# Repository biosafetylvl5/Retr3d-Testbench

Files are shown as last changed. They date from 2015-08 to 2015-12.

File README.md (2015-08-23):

# Retr3d Testbench
**Retr3d Testbench**, or just **Testbench** is an Arduino Mega shield build to enable self-testing. It uses resistors to check the current sinking of each pin after it checks if any pins are stuck HIGH or LOW.

## Images

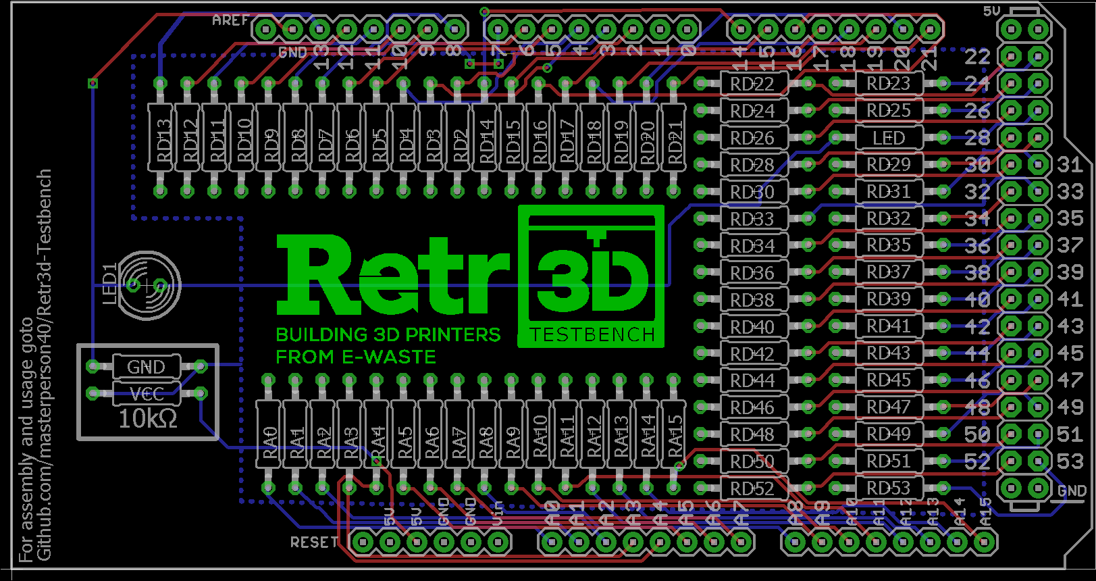
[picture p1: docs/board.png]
Board

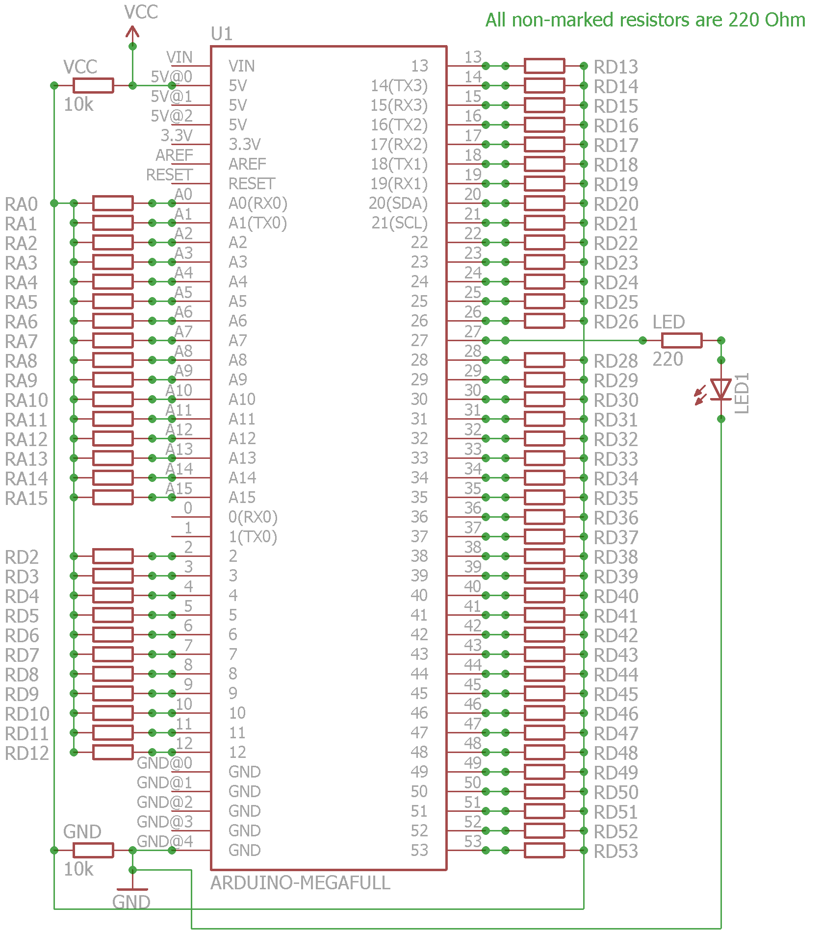
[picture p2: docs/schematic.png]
Schematic


## Origin
**Testbench** was designed to be used in tandem with Retr3d, a framework for designing custom 3D printers to be made out of e-waste. Cheap Arduino Mega clones have a relatively high failure rate, and **Testbench** hopes to find problem boards before they become a problem. With this in mind, certain design choices were made (see **Note 2**) that reflect this origin.

### Notes

##### Note 1:
Pins **0** and **1** are not tested because they must be used to upload the self-testing sketch, and therefore are assumed to be working. 

##### Note 2:

Pin **27** is not tested because it is a pin not utilized in the RAMPS 1.4 3D printer shield and instead is utilized to blink the indicator LED.

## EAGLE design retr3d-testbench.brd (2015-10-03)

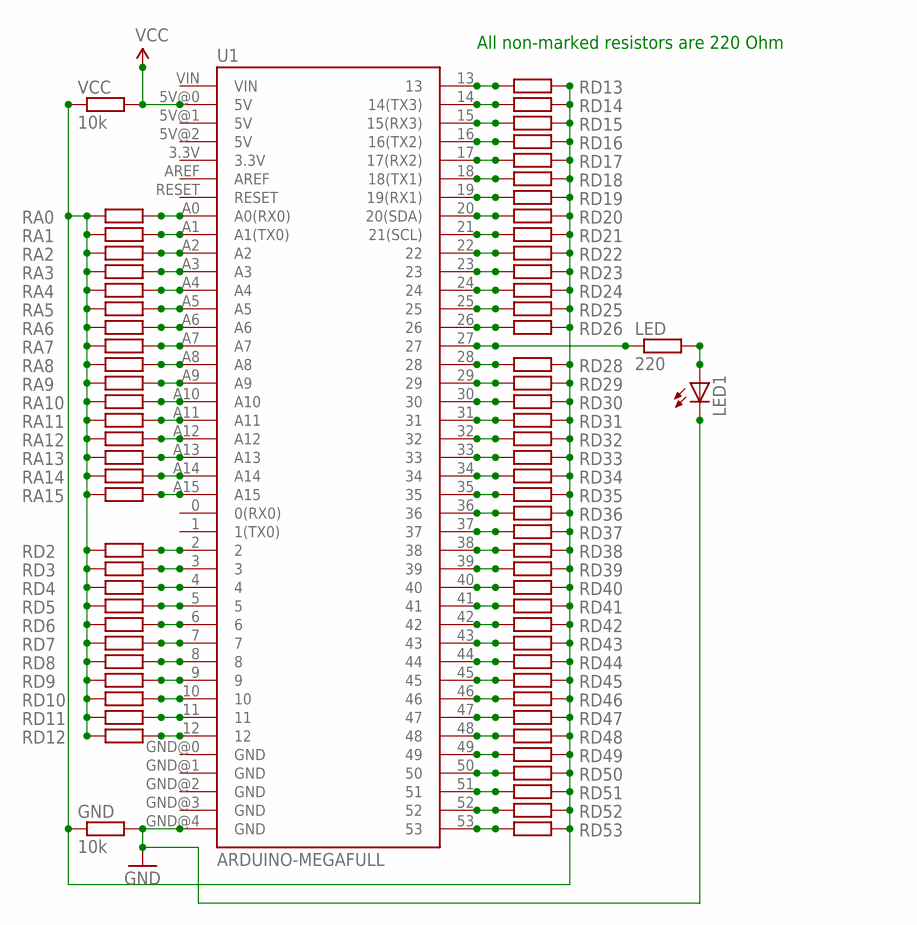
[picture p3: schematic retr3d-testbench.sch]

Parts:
GND: 10k; 0207/10
LED: 220; 0207/10
LED1: LED5MM
RA0, RA1, RA2, RA3, RA4, RA5, RA6, RA7, RA8, RA9, RA10, RA11, RA12, RA13, RA14, RA15: 220; 0207/10
RD2, RD3, RD4, RD5, RD6, RD7, RD8, RD9, RD10, RD11, RD12, RD13, RD14, RD15, RD16, RD17, RD18, RD19, RD20, RD21, RD22, RD23, RD24, RD25, RD26, RD28, RD29, RD30, RD31, RD32, RD33, RD34, RD35, RD36, RD37, RD38, RD39, RD40, RD41, RD42, RD43, RD44, RD45, RD46, RD47, RD48, RD49, RD50, RD51, RD52, RD53: 220; 0207/10
U1: ARDUINO-MEGAFULL; ARDUINO_MEGA
VCC: 10k; 0207/10

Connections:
GND: GND.2, LED1.K (C), U1.GND@4 (GND)
unnamed: RD13.1, U1.13
unnamed: LED.1, U1.27
unnamed: RA0.2, U1.A0 (A0(RX0))
unnamed: LED.2, LED1.A
unnamed: RD15.1, U1.15 (15(RX3))
unnamed: RA2.2, U1.A2
unnamed: RA4.2, U1.A4
unnamed: RD17.1, U1.17 (17(RX2))
unnamed: RA6.2, U1.A6
unnamed: RA8.2, U1.A8
unnamed: RD19.1, U1.19 (19(RX1))
unnamed: RA10.2, U1.A10
unnamed: RA11.2, U1.A11
unnamed: RA12.2, U1.A12
unnamed: RA13.2, U1.A13
unnamed: RD21.1, U1.21 (21(SCL))
unnamed: RA14.2, U1.A14
unnamed: RA15.2, U1.A15
unnamed: RD22.1, U1.22
unnamed: RD2.2, U1.2
unnamed: RD3.2, U1.3
unnamed: RD5.2, U1.5
unnamed: RD24.1, U1.24
unnamed: RD4.2, U1.4
unnamed: RD6.2, U1.6
unnamed: RD7.2, U1.7
unnamed: RD9.2, U1.9
unnamed: RD26.1, U1.26
unnamed: RD8.2, U1.8
unnamed: RD10.2, U1.10
unnamed: RD11.2, U1.11
unnamed: RD12.2, U1.12
unnamed: RD28.1, U1.28
unnamed: RD14.1, U1.14 (14(TX3))
unnamed: RD16.1, U1.16 (16(TX2))
unnamed: RD30.1, U1.30
unnamed: RD18.1, U1.18 (18(TX1))
unnamed: RD20.1, U1.20 (20(SDA))
unnamed: RD32.1, U1.32
unnamed: RD23.1, U1.23
unnamed: RD25.1, U1.25
unnamed: RD29.1, U1.29
unnamed: RD31.1, U1.31
unnamed: RD33.1, U1.33
unnamed: RD34.1, U1.34
unnamed: RD38.1, U1.38
unnamed: RD35.1, U1.35
unnamed: RD36.1, U1.36
unnamed: RD37.1, U1.37
unnamed: RD39.1, U1.39
unnamed: RD40.1, U1.40
unnamed: RD41.1, U1.41
unnamed: RD42.1, U1.42
unnamed: RD43.1, U1.43
unnamed: RD44.1, U1.44
unnamed: RD45.1, U1.45
unnamed: RD46.1, U1.46
unnamed: RD47.1, U1.47
unnamed: RD53.1, U1.53
unnamed: RD52.1, U1.52
unnamed: RD51.1, U1.51
unnamed: RD50.1, U1.50
unnamed: RD49.1, U1.49
unnamed: RD48.1, U1.48
unnamed: RA1.2, U1.A1 (A1(TX0))
unnamed: RA3.2, U1.A3
unnamed: RA5.2, U1.A5
unnamed: RA7.2, U1.A7
unnamed: RA9.2, U1.A9
N$TEST: GND.1, RA0.1, RA1.1, RA2.1, RA3.1, RA4.1, RA5.1, RA6.1, RA7.1, RA8.1, RA9.1, RA10.1, RA11.1, RA12.1, RA13.1, RA14.1, RA15.1, RD2.1, RD3.1, RD4.1, RD5.1, RD6.1, RD7.1, RD8.1, RD9.1, RD10.1, RD11.1, RD12.1, RD13.2, RD14.2, RD15.2, RD16.2, RD17.2, RD18.2, RD19.2, RD20.2, RD21.2, RD22.2, RD23.2, RD24.2, RD25.2, RD26.2, RD28.2, RD29.2, RD30.2, RD31.2, RD32.2, RD33.2, RD34.2, RD35.2, RD36.2, RD37.2, RD38.2, RD39.2, RD40.2, RD41.2, RD42.2, RD43.2, RD44.2, RD45.2, RD46.2, RD47.2, RD48.2, RD49.2, RD50.2, RD51.2, RD52.2, RD53.2, VCC.1
VCC: U1.5V@0 (5V), VCC.2

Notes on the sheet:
All non-marked resistors are 220 Ohm

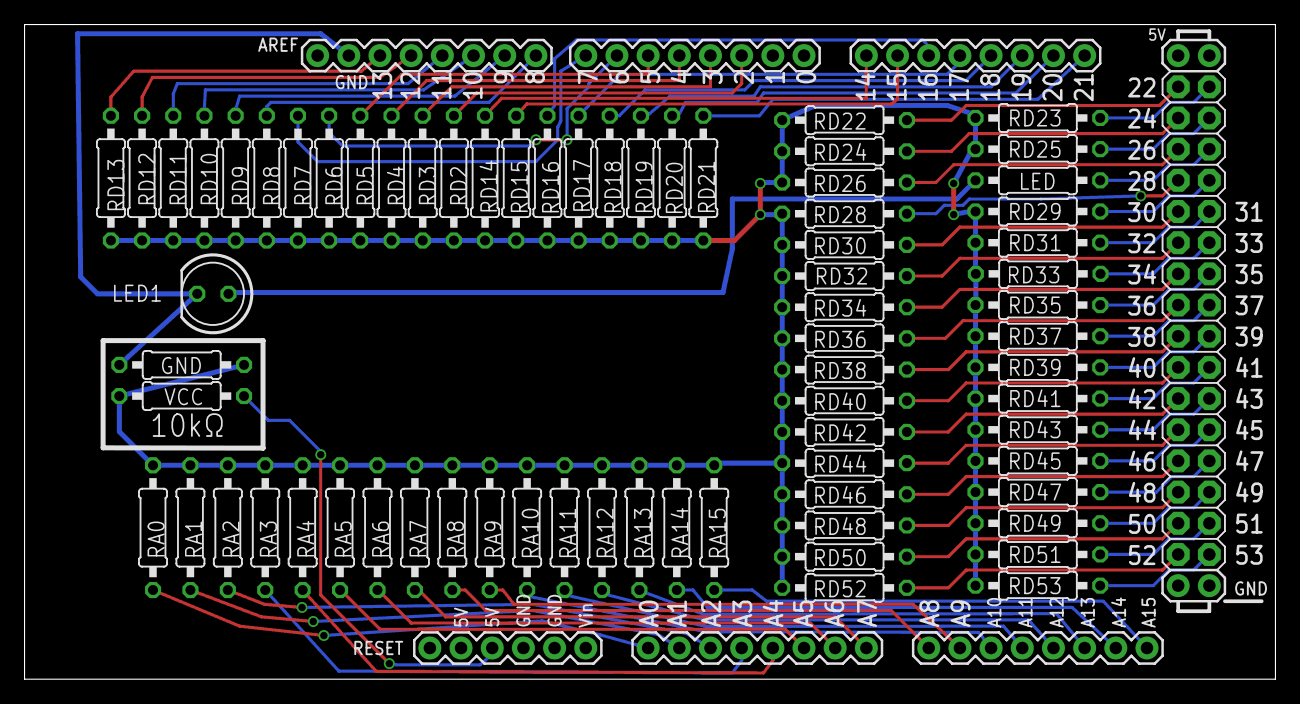
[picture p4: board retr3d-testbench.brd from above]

Board: 2 copper layers, 101.9 x 53.3 mm, 72 parts (0 on the bottom side), 72 nets.

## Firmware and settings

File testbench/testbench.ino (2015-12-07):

int pinNum = 50; //Number of digital pins to be tested
int ledPin = 27; //LED pin
int pins[] = {2, 3, 4, 5, 6, 7, 8, 9, 10, 11, 12, 13, 14, 15, 16, 17, 18, 19, 20, 21, 22, 23, 24, 25, 26, 28, 29, 30, 31, 32, 33, 34, 35, 36, 37, 38, 39, 40, 41, 42, 43, 44, 45, 46, 47, 48, 49, 50, 51, 52}; // Pins to be tested, exluding pins 0, 1, and 27
int aPins[] = {A0, A1, A2, A3, A4, A5, A6, A7, A8, A9, A10, A11, A12, A13, A14, A15}; //List of analog pins to be tested
int aPinNum = 16; //Number of analog pins to be tested



int analogPin; //Used to record "working" analog pins for program use
int digitalPin; //Used to record "working" digital pins for program use
int failed = 0; //Used to record whether the Arduino has passed, 0 = passed and 1 = failed

// the setup routine runs once when you press reset:
void setup() {
  // initialize serial communication at 9600 bits per second
  Serial.begin(9600);

  //Have LED remain solid during the test
  pinMode(ledPin, OUTPUT);
  digitalWrite(ledPin, HIGH);

    //Initialize all pins to INPUT
    for (int thisPin = 0; thisPin < pinNum; thisPin++) {
      pinMode(pins[thisPin], INPUT);
    }

    //Check if any pins are stuck
    float pinReading = (float(analogRead(analogPin))/float(1023))*float(5);
    if((pinReading > 2.4)&&(pinReading < 2.6)){Serial.print("PINS ARE NOT STUCK: ");}else{Serial.print("PINS ARE STUCK: "); failed=1;} // If voltage too far from normal, pins are considered to be stuck
    Serial.print(pinReading); // Print findings
    Serial.println(" V");

    //Set all digital pins to OUTPUT and then set them to HIGH
    for (int thisPin = 0; thisPin < pinNum; thisPin++) {
      pinMode(pins[thisPin], OUTPUT);
      digitalWrite(pins[thisPin], HIGH);
    }

    //Test all analog pins to see if they register voltage correctly
    for (int thisPin = 0; thisPin < aPinNum; thisPin++) {
      int pinReading = analogRead(pins[thisPin]); //Check to see if analog pins read 5v from all the HIGH digital pins
      
      //Set all digital pins to LOW
      for (int thisPin = 0; thisPin < pinNum; thisPin++) {
        digitalWrite(pins[thisPin], LOW); 
      }

      int pinReadingTwo = analogRead(pins[thisPin]);//Check to see if analog pins read 0v from all the LOW digital Pins

      //Set all digital pins to HIGH
      for (int thisPin = 0; thisPin < pinNum; thisPin++) {
        digitalWrite(pins[thisPin], HIGH);
      }

      //Report results via serial
      if((pinReading > 1020)&&(pinReadingTwo < 20)){ //If pin readings read 5v and 0v, pins are good
        Serial.print("Analog Pin ");
        Serial.print(thisPin);
        Serial.println("  --GOOD--");
        analogPin = aPins[thisPin];
      }else{
        Serial.print("Analog Pin ");
        Serial.print(thisPin);
        Serial.println("  --BAD--");
        failed=1; //If pins are bad, the test has been failed
      }
    }

    //Revert all digital pins to INPUT
    for (int thisPin = 0; thisPin < pinNum; thisPin++) {
      pinMode(pins[thisPin], INPUT);
    }

    
    for (int thisPin = 0; thisPin < pinNum; thisPin++) {
      int highPin;
      int highPinTwo;
      if(thisPin==0){ // Loop array around to avoid pins that don't exist
        highPin = pinNum; //Set pin to last pin
      if(thisPin==0){ // Loop array around to avoid pins that don't exist
        highPinTwo = 0; //Set pin to first pin
      }else{
        if(pins[thisPin]-1==ledPin){ //Skip ledPin
          highPin = pins[thisPin]-2;
        }else{
          highPin = pins[thisPin]-1;
        }
        if(pins[thisPin]+1==ledPin){
          highPinTwo = pins[thisPin]+2;
        }else{
          highPinTwo = pins[thisPin]+1;
        }
      }
      }
      
      pinMode(pins[thisPin], OUTPUT); //Set pin to OUTPUT
      digitalWrite(pins[thisPin], LOW); //Set pin LOW
      pinMode(highPin, OUTPUT); //Set high pin to OUTPUT
      digitalWrite(highPin, HIGH); //Set high pin to HIGH
      pinMode(highPinTwo, OUTPUT); //Set backup high pin to OUTPUT
      digitalWrite(highPinTwo, HIGH); //Set backup high pin to HIGH
      
      delay(1); // delay in between reads for stability
      float pinReading = (float(analogRead(analogPin))/float(1023))*float(5); // Read analog voltage and convert it to 0-5v
      
      pinMode(pins[thisPin], INPUT); //Reset pin
      pinMode(highPin, INPUT); //Reset high pin
      pinMode(highPinTwo, INPUT); //Reset backup high pin

      //Report back to user
      Serial.print("Digital Pin ");
      Serial.print(pins[thisPin]);
      Serial.print(": ");
      Serial.print(pinReading);        

      //Report whether or not the pin passed 
      if((pinReading > 2.4)&&(pinReading < 2.6)){
        Serial.print("     --GOOD--SINKS CURRENT--");  
        digitalPin = pins[thisPin];
      }else{
        Serial.print("     --BAD--CANNOT SINK CURRENT--"); 
        failed=1; // Pin failed the test, set failed to 1
      }
      
      Serial.println(); //End serial line
      delay(100); //Delay for readablility
    }
    
      pinMode(digitalPin, OUTPUT); //Use working pin to test other pins
      digitalWrite(digitalPin, LOW); //Set working pin to LOW

      //Test pins for their ablility to source current
      for (int thisPin = 0; thisPin < pinNum; thisPin++) {
        pinMode(pins[thisPin], OUTPUT); //Set pin to OUTPUT
        digitalWrite(pins[thisPin], HIGH); //Set pin to HIGH
        delay(1); // delay in between reads for stability
        float pinReading = (float(analogRead(analogPin))/float(1023))*float(5); //Read analog voltage and convert to 0-5v 
        
        pinMode(pins[thisPin], INPUT); //Reset pin to INPUT
        
        Serial.print("Digital Pin "); //Report to user pin findings
        Serial.print(pins[thisPin]); 
        Serial.print(": ");
        Serial.print(pinReading);        

        //Report if pin passed or not
        if((pinReading > 2.4)){
          Serial.print("     --GOOD--SOURCES CURRENT--"); 
          digitalPin = pins[thisPin];
        }else{
          Serial.print("     --BAD--CANNOT SOURCE CURRENT--"); 
          failed=1; //Set faild to 1 because pin failed the test
        }
        
        Serial.println(); //End serial line
        delay(100); //Delay for readablity
      }
      
    pinMode(digitalPin, INPUT); //Reset digitalPin to INPUT   

  }

void loop() {
  
  if(failed==0){ //If the board passed, blink slow
    digitalWrite(ledPin, HIGH);   // turn the LED on (HIGH is the voltage level)
    delay(1000);              // wait for a second
    digitalWrite(ledPin, LOW);    // turn the LED off by making the voltage LOW
    delay(1000);              // wait for a second
  }else{ //If the board failed, blink fast
    digitalWrite(ledPin, HIGH);   // turn the LED on (HIGH is the voltage level)
    delay(100);              // wait for a second
    digitalWrite(ledPin, LOW);    // turn the LED off by making the voltage LOW
    delay(100);              // wait for a second
  }
  
}

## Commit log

2015-08-23 Cropped board.png
2015-10-01 Hatched polygon for easier soldering
    [retr3d-testbench.brd]
2015-10-03 Redesign for easier fabrication
    [retr3d-testbench.brd]
2015-12-07 Fixed a possibility for errors
    [testbench.ino]

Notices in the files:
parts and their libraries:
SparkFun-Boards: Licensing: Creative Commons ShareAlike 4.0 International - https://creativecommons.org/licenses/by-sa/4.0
